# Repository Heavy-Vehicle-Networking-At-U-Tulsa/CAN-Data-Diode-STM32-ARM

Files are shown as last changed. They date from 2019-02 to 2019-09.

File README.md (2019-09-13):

# CAN Data Security Diode STM32 ARM
The code and documentation in this repository support a version of the CAN Data Security Diode that uses an ARM Cortex-M0 Processor with a CAN Controller made by ST. The specific chip use in this design is the [STM32F042K4](https://www.st.com/content/st_com/en/products/microcontrollers/stm32-32-bit-arm-cortex-mcus/stm32-mainstream-mcus/stm32f0-series/stm32f0x2/stm32f042k4.html).

## Documentation
The CAN Data Diode was presented at the 2019 ESCAR USA conference in Ypsilanti, MI. The [presentation slide deck](docs/2019_ESCAR_US_Daily2_Lecture.pdf) is in the docs folder. The [extended abstract](docs/CAN_Data_Diode_Abstract.pdf) aslo describes the system and the way it works. The design and production documents are available in this repository. 

## Source Code
The source code in this repository is built on [Example Code snippets](https://www.st.com/content/st_com/en/products/embedded-software/mcus-embedded-software/stm32-embedded-software/stm32snippets/stm32snippetsf0.html) covering STM32 F0 series.

## Hardware Documentation
The [documentation for the hardware](docs/README.md) includes schematics, production, files and original Altium Designer files.

## License


This work is licensed under a [Creative Commons Attribution-NonCommercial-ShareAlike 4.0 International License](http://creativecommons.org/licenses/by-nc-sa/4.0/) with the following addenda:

### Section 9 - Licensor
The Licensor for the works in this repository, unless otherwise noted, is The University of Tulsa, 800 S. Tucker Dr., Tulsa, OK, 74104. All inquiries regarding the potential for commercialization should be directed to the Office of Research and Sponsored Programs. 

### Section 10 - Licenced Material
The Licensed Material is the CAN Data Diode hardware design, which includes schematics, assembly instructions and documents (i.e. Gerber Files, NC Drill files, pick-and-place files, and the bill of materials). Unless otherwise noted in the source files, source code in this repository is included in the Licenced Material.

## Commercial Use
For commercial applications, please contact the University of Tulsa's Office of Research and Sponsored Programs for licensing opportunities.

## Acknowledgments
The authors and designers would like to acknowledge the support of the National Motor Freight Traffic Association, Inc. (NMFTA) in creating this device. Their leadership in the promoting and improving cybersecurity of heavy vehiles should not go unnoticed.

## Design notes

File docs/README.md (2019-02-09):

# CAN Data Diode Production Files and Documentation

This documentation directly focuses on the hardware design and production of the CAN Data Diode.

So long as the terms of the license are met, you can use these production and documentation files to fabricate, evaluate, and test the CAN Data Diode. 

## Documentation
The documentation consists of the following documents:

  1. The schematic drawing of the circuit used for the CAN Data Diode with the STM32F0 processors.
  1. A Bill of Materials in MS Excel and PDF formats.

## Production Files
The production files contain a zip compressed folder with the Gerber files, pick-and-place files, bill of materials, and NC drill files. This single zip file can be sent to an electronics fabrication facility for a full turn-key prodution. For example, Electronic Manufacturing Solutions, Inc. out of Lincoln, AR can produce these boards with the contents of this production file.

## Altium Files
The printed circuit board project files including the PCB layout and schematic are available. This is the so-called source code of the hardware for the CAN Data Diode. 

## Errata
On the first run articles produced in 2018, the Diodes D1 and D2 were mounted backwards. After orienting them correctly, the system powers on correctly.

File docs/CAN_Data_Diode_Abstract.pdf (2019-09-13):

Controller Area Network Security Data Diode Extended Abstract
Introduction
A controller area network (CAN) security data diode converts a stub of the linear CAN bus from being able to read and write to read-only. This effectively isolates a network node by preventing it from writing data to the network. The CAN data diode is a hardware-based solution that gives system integrators and vehicle owners the ability to take active steps in preventing any detrimental CAN traffic from affecting the normal operation of a vehicle. The original concept for the CAN security data diode was to isolate electronic logging devices (ELDs) on heavy vehicles, but the hardware device can be used to isolate any read-only node on a CAN bus (e.g. a radio).

### Problem Statement

Even though the controller area network protocol has reliable delivery mechanisms built in with the
acknowledgment field, CAN lacks message authentication mechanisms at the protocol level. This means unintended or malicious network traffic can be introduced to the system without recourse. Devices connected to the vehicle CAN networks are capable of both receiving and sending information with equal access to the direct-link vehicle network. A cybersecurity breach in any of the connected controller applications affecting the CAN communications can lead to serious consequences.
In new vertically integrated vehicle systems a designer can specify some application layer authentication mechanisms like checksums, or cryptographic message authentication code (CMAC). However, in legacy systems, aftermarket device installations, or horizontally integrated industries, like heavy vehicles, the ability to implement application layer protections is challenging. Furthermore, federal regulations, like the ELD mandate for heavy vehicles, may require the installation of wirelessly connected devices to a vehicle. The introduction of these ELD devices to the SAE J1939 network is required on all trucks that are so equipped, which reaches back as far as model year 2000 vehicles. Legacy fleets are now required to have wirelessly enabled electronic devices connected to the same controller area network that is used by the brakes, engine, instrument cluster. Vehicle manufacturers have little influence on the quality and security of the ELD devices connected on their vehicles.
Implementation
The CAN security data diode works by using two CAN transceivers in a configuration such that the transceiver connected to the main CAN bus (let’s call this the J1939 transceiver) has its receive data line (RXD) connected to the transmit data line (TXD) of a transceiver connected to the isolated node (let’s call this the ELD transceiver). This would act as a CAN relay where the J1939 transceiver would convert the differential CAN signal into a logic signal which is sent to the ELD transceiver to be converted back to the differential CAN signal. There is no inspection of or filtering of the data, so latency is minimized. However, the reverse connection is not made, so any data received from the ELD transceiver that would be sent out on the TXD logic pin is not received by the J1939 transceiver. Removing the connection from RXD of the ELD transceiver to the TXD of the J1939 transceiver eliminates the ability for messages generated from the isolated node to be seen on the main CAN bus.
Since the physical implementation of the diode functionality is based solely on hardware transceivers, there is no way for a software vulnerability to exist in the diode. To attack or circumvent the CAN data diode itself, someone could physically remove it from the wiring harness.
Dealing with messages on isolated nodes
While the intended use of the CAN security data diode is to enforce a read-only policy, there may be times when the isolated node would legitimately respond. For example, an isolated device may respond to a request for component information defined in SAE J1939. Another example is address claiming according to the SAE J1939 specification. If the back-to-back transceiver solution is deployed on its own, then the network on the isolated ELD side would be incomplete. Since the CAN controller is responsible for sending acknowledgment bits for received messages, the transceiver only implementation would not be able to satisfy this functionality. Without the ability for the isolated device to have its messages acknowledged, the messages will retry and accumulate errors. This may affect the functionality of the isolated device as it would be in an error state.

To alleviate the issue for a lack of acknowledgement, another CAN node needs to be present on the isolated bus. This node needs to contain both a controller and a transceiver with settings to match the bitrate of the original communications system. This new node on the isolated side of the network is build into the CAN data diode and is called the Acknowledger node.
Another challenge for an isolated ELD node when sending messages is arbitration. For the non-destructive media access control solution used by CAN to work, the nodes on the network need to be able to monitor the bus. When isolating a node, then the rest of the nodes cannot detect when the isolated node tries to transmit data. This means the main CAN bus will detect a quiet bus, even if the isolated node tries to transmit. Since the bus is quiet, the nodes on the J1939 side may begin transmitting, even if the isolated node is in the middle of transmitting a message. If this happens, bits may be flipped, or the CAN structure may be violated, and the isolated node will detect that it did not receive what it sent. This will initiate the error handling process on the isolated node. This process will likely try to send the message again during the next bus quiet phase, but the same issue may come up again. During times with heavy busloads, the process may repeat enough times for the isolated node on the ELD network to accumulate enough transmit error counts to enter an error passive or bus off state.
To prevent the effect of a so-called “chatty” main CAN bus sending the isolated node into an error state, the Acknowledger node built into the data diode will track error counts and be able to silence the ELD transceiver that is forwarding the busy traffic from the main CAN bus. This temporary respite for the isolated node enables a successful transmission from the isolated node on the ELD side of the network, which keeps the isolated node from going into an error passive or bus-off state.
ELD Request Proxy
In the case of an ELD that is governed by regulation, there are certain data elements that need to be requested according to the SAE J1939 standard. These elements include engine hours and vehicle identification number. Since these elements are required, it is likely that an ELD would request them using the SAE J1939 parameter group number for requesting data. However, if the ELD is isolated and cannot request this information, another device on the network must provide it. In some cases, these messages are requested by and among the modules already on the network. However, if they are not readily available during normal operation, then a so-called requester node will need to act as a requesting proxy for the ELD. This purpose-built device can be integrated into the CAN data diode or installed as a separate device. The requester should only request data elements if they are not already present. Both ISO 14229 messages and SAE J1939 message should be examined to look for the required data elements. Hardware Circuit Description
A reference design, as shown in the Appendix, was built using STMicroelectronics’ STM32F042G4 ARM Cortex-M0 microprocessors with built-in CAN controllers. These were coupled with Texas Instruments’ CAN transceivers from the TCAN33X family. In quantities of 100, the price per unit (including the enclosure) was $53.96 with USbased manufacturing for the prototype units.
There are four CAN transceivers; two of the transceivers are dedicated to the data diode functionality. The data diode transceivers are the TI-TCAN330 devices with silent mode and shutdown mode. The silent mode is controlled on pin 8 of the transceiver and is connected to the Acknowledger microprocessor. If the Acknowledger detects receive errors, which are likely from interference between the isolated node and the main CAN bus, then it will put the ELD transceiver into silent mode to prevent the transmission of data from the main bus to the isolated bus. The J1939 transceiver is always in silent mode. Pin 5 of the data diode transceivers are used to toggle the shutdown modes for the system to reduce power when the CAN bus is silent.
The remaining two CAN transceivers are connected to the STM32F0 processors. These are the TI TCAN334 that have a shutdown mode and a low power standby mode with wake. The standby mode enables the transceiver to wake with network traffic and to inform the requester microcontroller to activate the remaining transceivers. After a timeout period of low or reduced traffic, the microprocessors will enable the transceivers’ low power modes.
When a CAN security data diode is installed, it will automatically determine the best bit timing to match the bitrate of the vehicle network. The two most popular choices are 250,000 bps and 500,000 bps. The process of automatically determining the bitrate, or autobaud feature, leverages the receive error counter (REC) functionality of the CAN controller. The initial guess for the bit timing is loaded from a register in EEPROM. If REC increases when new messages arrive, a new value is tried until messages arrive. The new value is stored in the EEPROM, which will keep the unit from iterating over the valid bit timing combinations if the device is installed on the same vehicle (or a CAN bus with the same rate).
The CAN terminating resistors are also isolated with the CAN Data diode. Therefore, the ELD and Acknowledger transceivers are connected to a differential pair that has 60 ohms of resistance across the pair. Examination of the wave forms as observed with an oscilloscope on the differential signaling pair on either side of the CAN Data diode shows there is no recognizable lag in the signals from one side to another. In other words, any delay in the signal is influenced only by electronic wave propagation in the semiconductors since there is no filtering mechanism in place. The physical connectors to the CAN data diode reference use a DSUB 15 connector with two rows. The industry standard pinout has battery power on pin 8, ignition signal on pin 1, ground on pin 6, J1939H on pin 13, and J1939L on Pin 12. All other pins pass through. The raw battery and ignition connections are reverse polarity protected with a Schottky diode. Conductive noise suppression is handled by a hybrid varistor. Noise and Electrostatic Discharge protections are built into the CAN transceivers. All components selected for the reference build are AEC rated for an automotive environment.
If an ignition signal line is not present at the location of installation, then a resistor connects the conductive path for the ignition signal to the raw battery line, which pulls the ignition signal high. The Infineon linear Low Dropout (LDO) regulator supplies 3.3V to the board with a maximum current draw of 100mA when the enable pin is pulled high. The ignition line is connected to the enable pin for a hardware-based power regulation system. If the ignition line is not independent of the battery voltage, then the programming in the microprocessors will need to manage current draw when the vehicle is off. The reference design draws about 30 mA when on. The software for the Acknowledger and the Requester are programs that implement their necessary functions of initializing the hardware systems, setting the bit rates, and scheduling the processes for performing the requests and power monitoring. A CAN based updating systems was purposely not implemented as changes to the CAN data diode will need to be done with physical access. For the reference hardware, programming is done using a SWD enabled JTAG device. The board has the Cortex -M headers with ten pins (fine pitched). These programs are needed to isolate the ELD for heavy trucks and manage power saving features. The programming and debugging headers on the printed circuit board are to the outside of the rest of the functional circuits. This feature enables production without debug headers by simply changing the board outline.
Test Results
Test results up to 1 Mbps shows all CAN traffic flows from the J1939 side to the ELD side error free when the isolated ELD node is quiet. The acknowledger functions as desired can be observed through the CAN TX line sending out acknowledgment bits for every CAN message passing through the data diode. If the ELD side is “compromised” and tries a denial of service attack by flooding the bus, the CAN Data Diode isolates that attack and no disruption of the main CAN bus is noticed when observing with both an oscilloscope and a CAN data logger. Discussion and Conclusion
The CAN security data diode is well suited to isolate read-only nodes that may not have well understood security properties. Some of the earliest academic research by Koscher, et ali demonstrated a radio unit could be exploited to affect the CAN bus. If the radio does not need to write to the CAN bus, then the CAN data diode can guarantee read-only behavior and offers a robust security solution to protect against unknown security vulnerabilities in radio head units. Printed circuit board adaptations to accommodate J1962 OBD-II connectors are possible, which could enhance security for the diagnostic ports to accommodate installation of after-market devices to the diagnostics port. The CAN data diode is applicable wherever a read-only or monitoring device is installed, regardless of the vehicle or industry. Rail, busses, and maritime applications may have more opportunities for passengers to tamper with wiring or accessing the CAN bus in an unauthorized way. The CAN data diode can mitigate the effect of a threat actor accessing the CAN through a monitoring device. Asset tracking and data logging features are also good candidates to be isolated behind a CAN Data Diode. The CAN security data diode is a hardware-based solution to mitigate the effect of an exploited node on a CAN bus.

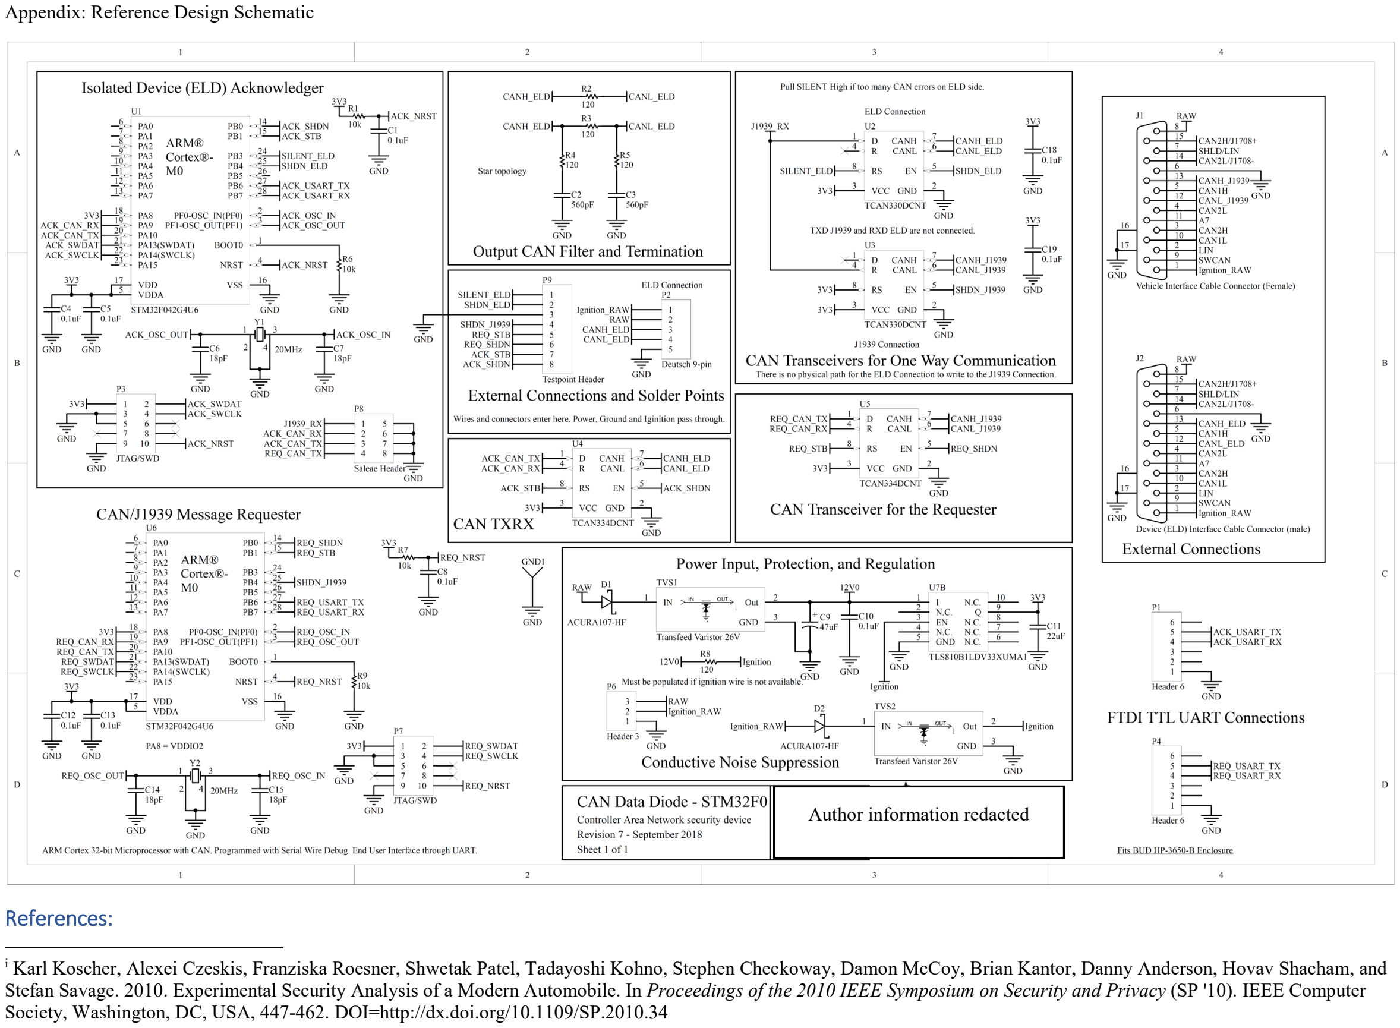
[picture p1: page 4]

Appendix: Reference Design Schematic

References:

i Karl Koscher, Alexei Czeskis, Franziska Roesner, Shwetak Patel, Tadayoshi Kohno, Stephen Checkoway, Damon McCoy, Brian Kantor, Danny Anderson, Hovav Shacham, and Stefan Savage. 2010. Experimental Security Analysis of a Modern Automobile. In Proceedings of the 2010 IEEE Symposium on Security and Privacy (SP '10). IEEE Computer Society, Washington, DC, USA, 447-462. DOI=http://dx.doi.org/10.1109/SP.2010.34

Author information redacted

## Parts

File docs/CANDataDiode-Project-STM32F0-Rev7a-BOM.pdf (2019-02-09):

Comment | Description | Designator | Footprint | Manufacturer 1 | Manufacturer Part Number 1 | Quantity | Supplier 1 | Supplier Part Number 1
0.1uF | 0.1µF ±10% 50V Ceramic Capacitor X7R 0402 (1005 Metric) | C1, C4, C5, C8, C10, C12, C13, C18, C19 | 0402 | TDK | CGA2B3X7R1H104K050BB | 9 | Digi-Key | 445-6899-1-ND
560pF | 560pF ±5% 50V Ceramic Capacitor CH 0402 (1005 Metric) | C2, C3 | 0402 | Taiyo Yuden | UMK105CH561JVHF | 2 | Digi-Key | 587-5093-1-ND
18pF | 18pF ±5% 50V Ceramic Capacitor C0G, NP0 0402 (1005 Metric) | C6, C7, C14, C15 | 0402 | Murata | GCM1555C1H180JA16D | 4 | Digi-Key | 490-12650-1-ND
47uF | 47µF 35V Aluminum Capacitors Radial, Can - SMD 5000 Hrs @ 105°C | C9 | Elec. Cap - D | Panasonic | EEE-HDV470XAP | 1 | Digi-Key | PCE4968CT-ND
22uF | 22µF ±20% 4V Ceramic Capacitor X7R 1206 (3216 Metric) | C11 | 1206 | Taiyo Yuden | AMK316AB7226MLHT | 1 | Digi-Key | 587-3267-1-ND
ACURA107-HF | Diode Schottky 1000V 1A Surface Mount DO-214AC (SMA) | D1, D2 | SMA with A and K | Comchip | ACURA107-HF | 2 | Digi-Key | 641-1884-1-ND
Vehicle Interface Cable Connector (Female) | Receptacle Assembly, 15 Position, Right Angle | J1 | DSUB1.385-2H15 | Amphenol FCI | D15S33E4GV00LF | 1 | Digi-Key | 609-1498-ND
Device (ELD) Interface Cable Connector (male) | Receptacle Assembly, 15 Position, Right Angle | J2 | DSUB1.385-2H15 | Amphenol FCI | D15P33E4GV00LF | 1 | Digi-Key | 609-1492-ND
10k | 10 kOhms ±0.5% 0.063W, 1/16W Chip Resistor 0402 (1005 Metric) Anti-Sulfur, Automotive AEC-Q200 Thin Film | R1, R6, R7, R9 | 0402 | Susumu | RG1005P-103-D-T10 | 4 | Digi-Key | RG10P10.0KDCT-ND
120 | 120 Ohms ±1% 0.063W, 1/16W Chip Resistor 0402 (1005 Metric) Automotive AEC-Q200 Thick Film | R2, R3, R4, R5, R8 | 0402 | Vishay | CRCW0402120RFKED | 5 | Digi-Key | 541-120LCT-ND
Transfeed Varistor 26V | 34.5V 80A Varistor 1 Circuit Surface Mount 0805 (2012 Metric) | TVS1, TVS2 | Transfeed | Kyocera AVX | V2AF126C600Y2EDP | 2 | Digi-Key | 478-10038-1-ND
STM32F042G4U6 | ARM® Cortex®-M0 STM32F0 Microcontroller IC 32-Bit 48MHz 16KB (16K x 8) FLASH 28-UFQFPN (4x4) | U1, U6 | STM-UFQFPN28_V | STMicroelectronics | STM32F042G4U6 | 2 | Digi-Key | 497-17830-ND
TCAN330DCNT | IC TXRX CAN 3.3V SOT23-8 | U2, U3 | SOT65P280X145-8N | Texas Instruments | TCAN330DCNT | 2 | Digi-Key | 296-44210-1-ND
TCAN334DCNT | IC TXRX CAN 3.3V SOT23-8 | U4, U5 | SOT65P280X145-8N | Texas Instruments | TCAN334DCNT | 2 | Digi-Key | 296-44503-1-ND
TLS810B1LDV33XUMA1 | Linear Voltage Regulator IC 1 Output 100mA PG-TSON-10 | U7 | SON50P330X110 _HS-11N | Infineon | TLS810B1LDV33XUMA1 | 1 | Digi-Key | TLS810B1LDV33XUMA1CT-ND
20MHz | 20MHz ±30ppm Crystal 18pF 60 Ohms 4-SMD, No Lead | Y1, Y2 | XTAL 4 pad | ECS International | ECS-200-18-33Q-DS | 2 | Digi-Key | XC1998CT-ND

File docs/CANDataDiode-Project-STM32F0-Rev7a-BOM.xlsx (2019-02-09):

Comment | Description | Designator | Footprint | Manufacturer 1 | Manufacturer Part Number 1 | Quantity | Supplier 1 | Supplier Part Number 1
0.1uF | 0.1µF ±10% 50V Ceramic Capacitor X7R 0402 (1005 Metric) | C1, C4, C5, C8, C10, C12, C13, C18, C19 | 0402 | TDK (https://octopart-clicks.com/click/altium?sku=445-6899-1-ND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) | CGA2B3X7R1H104K050BB (https://octopart-clicks.com/click/altium?sku=445-6899-1-ND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) | 9 | Digi-Key | 445-6899-1-ND (https://octopart-clicks.com/click/altium?sku=445-6899-1-ND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)
560pF | 560pF ±5% 50V Ceramic Capacitor CH 0402 (1005 Metric) | C2, C3 | 0402 | Taiyo Yuden (https://octopart-clicks.com/click/altium?sku=587-5093-1-ND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) | UMK105CH561JVHF (https://octopart-clicks.com/click/altium?sku=587-5093-1-ND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) | 2 | Digi-Key | 587-5093-1-ND (https://octopart-clicks.com/click/altium?sku=587-5093-1-ND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)
18pF | 18pF ±5% 50V Ceramic Capacitor C0G, NP0 0402 (1005 Metric) | C6, C7, C14, C15 | 0402 | Murata (https://octopart-clicks.com/click/altium?sku=490-12650-1-ND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) | GCM1555C1H180JA16D (https://octopart-clicks.com/click/altium?sku=490-12650-1-ND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) | 4 | Digi-Key | 490-12650-1-ND (https://octopart-clicks.com/click/altium?sku=490-12650-1-ND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)
47uF | 47µF 35V Aluminum Capacitors Radial, Can - SMD 5000 Hrs @ 105°C | C9 | Elec. Cap - D | Panasonic (https://octopart-clicks.com/click/altium?sku=PCE4968CT-ND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) | EEE-HDV470XAP (https://octopart-clicks.com/click/altium?sku=PCE4968CT-ND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) | 1 | Digi-Key | PCE4968CT-ND (https://octopart-clicks.com/click/altium?sku=PCE4968CT-ND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)
22uF | 22µF ±20% 4V Ceramic Capacitor X7R 1206 (3216 Metric) | C11 | 1206 | Taiyo Yuden (https://octopart-clicks.com/click/altium?sku=587-3267-1-ND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) | AMK316AB7226MLHT (https://octopart-clicks.com/click/altium?sku=587-3267-1-ND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) | 1 | Digi-Key | 587-3267-1-ND (https://octopart-clicks.com/click/altium?sku=587-3267-1-ND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)
ACURA107-HF | Diode Schottky 1000V 1A Surface Mount DO-214AC (SMA) | D1, D2 | SMA with A and K | Comchip (https://octopart-clicks.com/click/altium?sku=641-1884-1-ND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) | ACURA107-HF (https://octopart-clicks.com/click/altium?sku=641-1884-1-ND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) | 2 | Digi-Key | 641-1884-1-ND (https://octopart-clicks.com/click/altium?sku=641-1884-1-ND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)
Vehicle Interface Cable Connector (Female) | Receptacle Assembly, 15 Position, Right Angle | J1 | DSUB1.385-2H15 | Amphenol FCI (https://octopart-clicks.com/click/altium?sku=609-1498-ND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) | D15S33E4GV00LF (https://octopart-clicks.com/click/altium?sku=609-1498-ND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) | 1 | Digi-Key | 609-1498-ND (https://octopart-clicks.com/click/altium?sku=609-1498-ND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)
Device (ELD) Interface Cable Connector (male) | Receptacle Assembly, 15 Position, Right Angle | J2 | DSUB1.385-2H15 | Amphenol FCI (https://octopart-clicks.com/click/altium?sku=609-1492-ND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) | D15P33E4GV00LF (https://octopart-clicks.com/click/altium?sku=609-1492-ND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) | 1 | Digi-Key | 609-1492-ND (https://octopart-clicks.com/click/altium?sku=609-1492-ND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)
10k | 10 kOhms ±0.5% 0.063W, 1/16W Chip Resistor 0402 (1005 Metric) Anti-Sulfur, Automotive AEC-Q200 Thin Film | R1, R6, R7, R9 | 0402 | Susumu (https://octopart-clicks.com/click/altium?sku=RG10P10.0KDCT-ND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) | RG1005P-103-D-T10 (https://octopart-clicks.com/click/altium?sku=RG10P10.0KDCT-ND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) | 4 | Digi-Key | RG10P10.0KDCT-ND (https://octopart-clicks.com/click/altium?sku=RG10P10.0KDCT-ND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)
120 | 120 Ohms ±1% 0.063W, 1/16W Chip Resistor 0402 (1005 Metric) Automotive AEC-Q200 Thick Film | R2, R3, R4, R5, R8 | 0402 | Vishay (https://octopart-clicks.com/click/altium?sku=541-120LCT-ND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) | CRCW0402120RFKED (https://octopart-clicks.com/click/altium?sku=541-120LCT-ND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) | 5 | Digi-Key | 541-120LCT-ND (https://octopart-clicks.com/click/altium?sku=541-120LCT-ND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)
Transfeed Varistor 26V | 34.5V 80A Varistor 1 Circuit Surface Mount 0805 (2012 Metric) | TVS1, TVS2 | Transfeed | Kyocera AVX (https://octopart-clicks.com/click/altium?sku=478-10038-1-ND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) | V2AF126C600Y2EDP (https://octopart-clicks.com/click/altium?sku=478-10038-1-ND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) | 2 | Digi-Key | 478-10038-1-ND (https://octopart-clicks.com/click/altium?sku=478-10038-1-ND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)
STM32F042G4U6 | ARM® Cortex®-M0 STM32F0 Microcontroller IC 32-Bit 48MHz 16KB (16K x 8) FLASH 28-UFQFPN (4x4) | U1, U6 | STM-UFQFPN28_V | STMicroelectronics (https://octopart-clicks.com/click/altium?sku=497-17830-ND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) | STM32F042G4U6 (https://octopart-clicks.com/click/altium?sku=497-17830-ND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) | 2 | Digi-Key | 497-17830-ND (https://octopart-clicks.com/click/altium?sku=497-17830-ND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)
TCAN330DCNT | IC TXRX CAN 3.3V SOT23-8 | U2, U3 | SOT65P280X145-8N | Texas Instruments (https://octopart-clicks.com/click/altium?sku=296-44210-1-ND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) | TCAN330DCNT (https://octopart-clicks.com/click/altium?sku=296-44210-1-ND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) | 2 | Digi-Key | 296-44210-1-ND (https://octopart-clicks.com/click/altium?sku=296-44210-1-ND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)
TCAN334DCNT | IC TXRX CAN 3.3V SOT23-8 | U4, U5 | SOT65P280X145-8N | Texas Instruments (https://octopart-clicks.com/click/altium?sku=296-44503-1-ND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) | TCAN334DCNT (https://octopart-clicks.com/click/altium?sku=296-44503-1-ND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) | 2 | Digi-Key | 296-44503-1-ND (https://octopart-clicks.com/click/altium?sku=296-44503-1-ND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)
TLS810B1LDV33XUMA1 | Linear Voltage Regulator IC 1 Output 100mA PG-TSON-10 | U7 | SON50P330X110_HS-11N | Infineon (https://octopart-clicks.com/click/altium?manufacturer=Infineon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) | TLS810B1LDV33XUMA1 (https://octopart-clicks.com/click/altium?manufacturer=Infineon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) | 1 | Digi-Key | TLS810B1LDV33XUMA1CT-ND (https://octopart-clicks.com/click/altium?manufacturer=Infineon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)
20MHz | 20MHz ±30ppm Crystal 18pF 60 Ohms 4-SMD, No Lead | Y1, Y2 | XTAL 4 pad | ECS International (https://octopart-clicks.com/click/altium?sku=XC1998CT-ND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) | ECS-200-18-33Q-DS (https://octopart-clicks.com/click/altium?sku=XC1998CT-ND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) | 2 | Digi-Key | XC1998CT-ND (https://octopart-clicks.com/click/altium?sku=XC1998CT-ND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)

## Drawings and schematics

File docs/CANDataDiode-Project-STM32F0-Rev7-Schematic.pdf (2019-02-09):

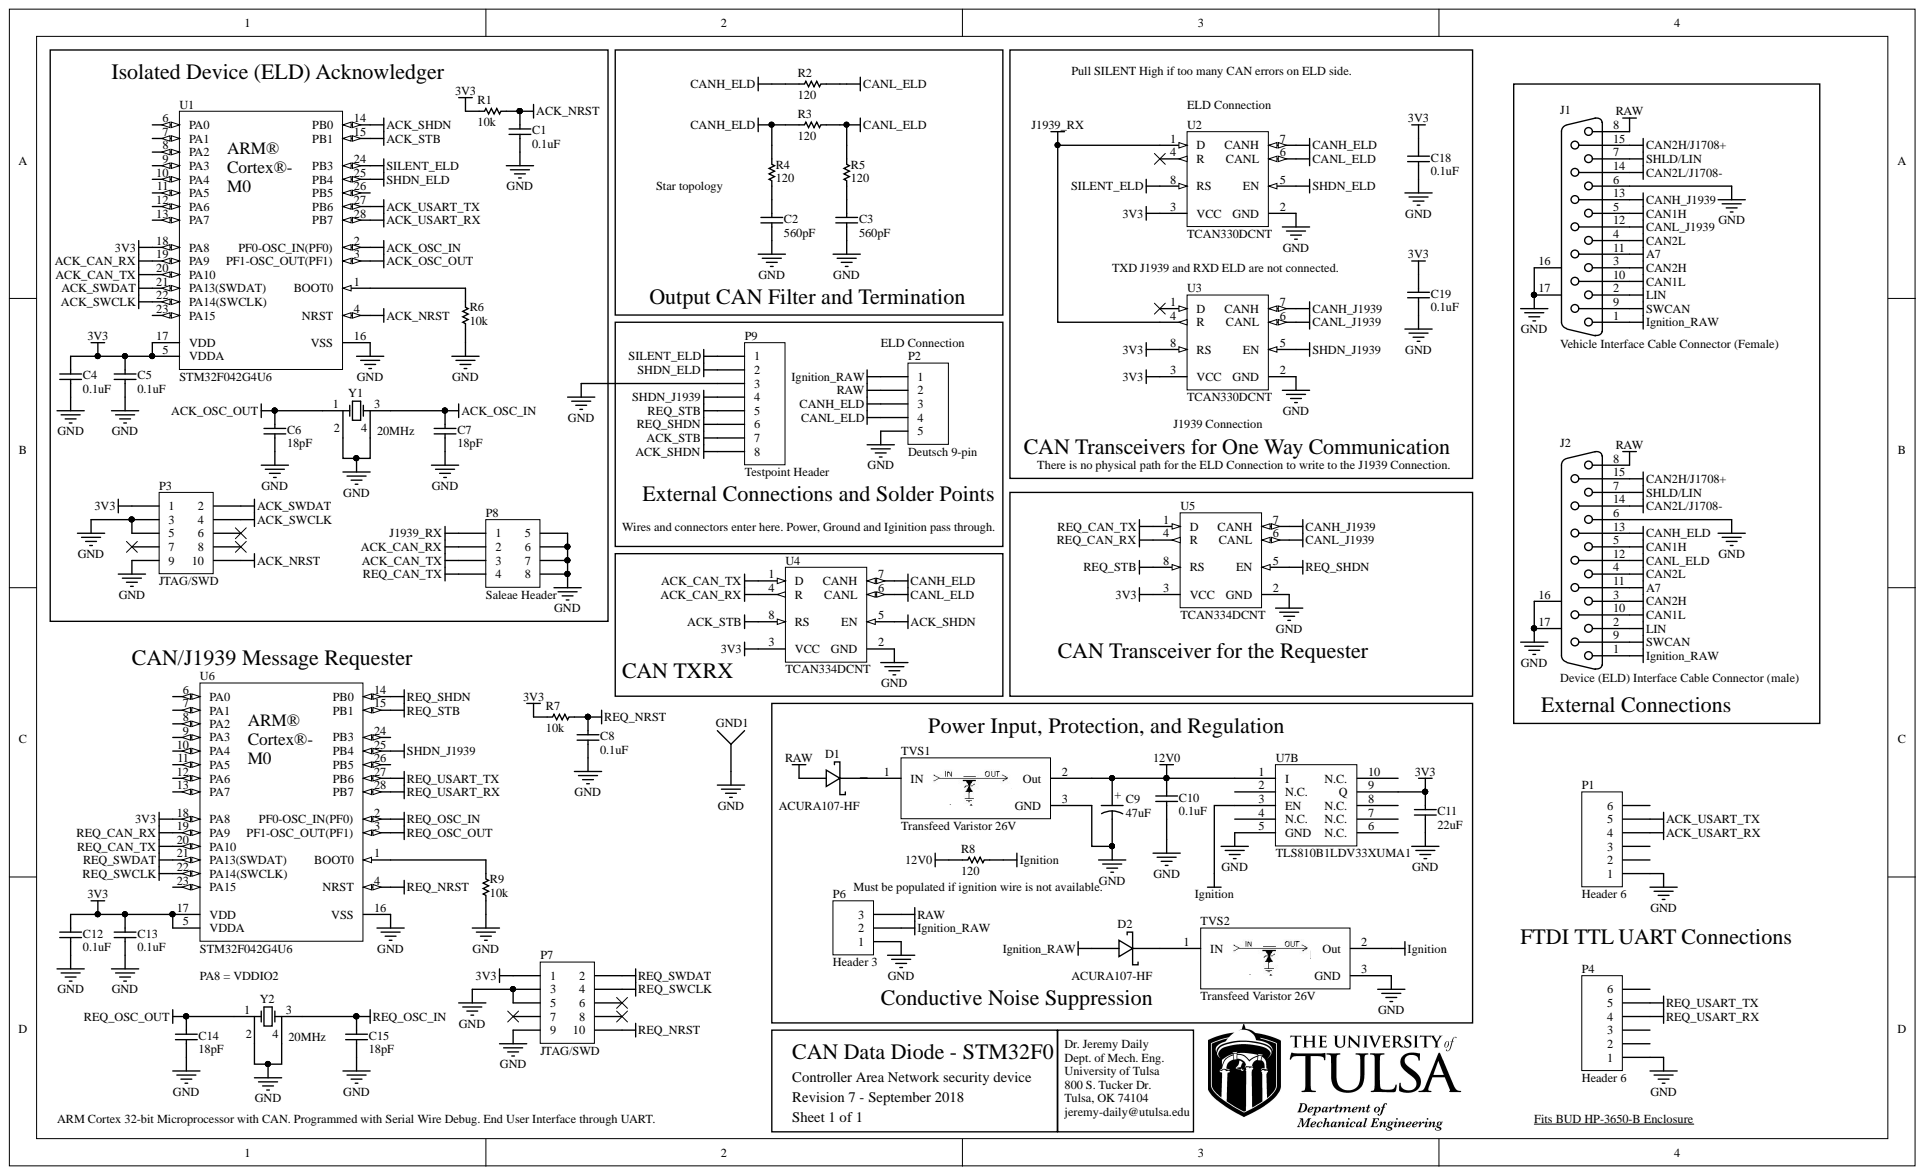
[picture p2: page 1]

Pull SILENT High if too many CAN errors on ELD side.

J1Vehicle Interface Cable Connector (Female)

TXD J1939 and RXD ELD are not connected.

Output CAN Filter and

There is no physical path for the ELD Connection to write to the J1939 Connection.

Wires and connectors enter here. Power

, Ground and Iginition pass through.

XRX CAN/J1939 Message Requester

Transceiver for the Requester

Device (ELD) Interface Cable Connector (male)
External Connections

Must be populated if ignition wire is not available.

Dept. of Mech. Eng.
University of
Tulsa, OK 74104
jeremy-daily@utulsa.edu

CAN Data Diode - STM32F0 Controller Area Network security device Revision 7 - September 2018

ARM Cortex 32-bit Microprocessor with CAN. Programmed with Serial

Wire Debug. End User Interface through UART

Fits BUD HP-3650-B Enclosure (https://www.budind.com/pdf/hb3650.pdf)

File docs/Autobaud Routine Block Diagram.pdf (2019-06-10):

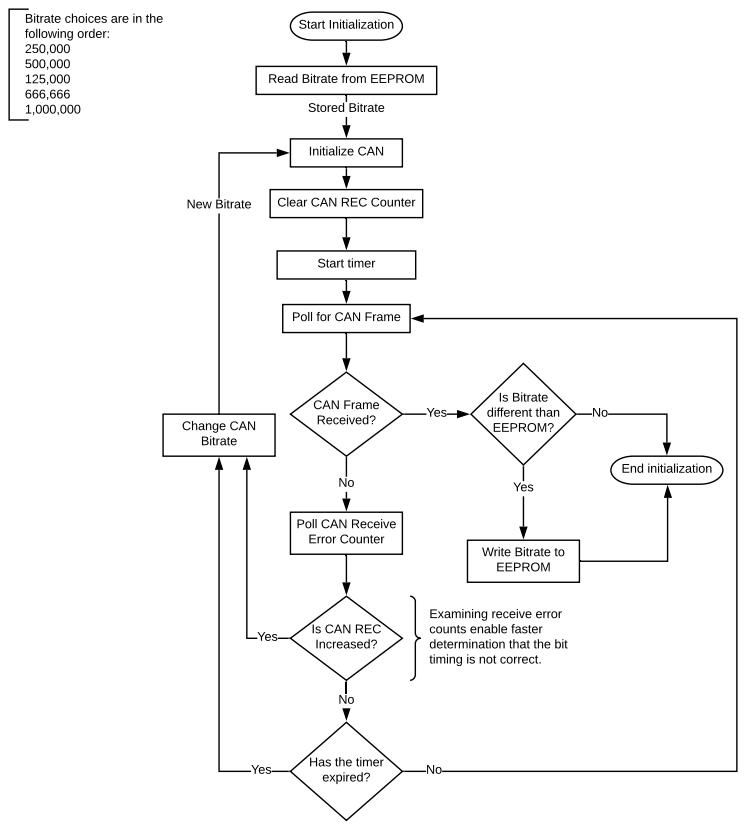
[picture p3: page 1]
Start Initialization; Initialize CAN; Stored Bitrate; CAN Frame Received?; Change CAN Bitrate; Yes; Is Bitrate different than EEPROM?; End initialization; expired? Yes; New Bitrate; Start timer; Bitrate choices are in the following order: 250,000 500,000 125,000 666,666 1,000,000

Read Bitrate from EEPROM

Clear CAN REC Counter

Poll for CAN Frame

Poll CAN Receive
Error Counter

Write Bitrate to
EEPROM

Examining receive error
counts enable faster
determination that the bit
timing is not correct.

Is CAN REC
Increased?

Has the timer

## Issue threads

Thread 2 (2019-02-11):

Copyright of `main.c` is assigned (incompatibly) to ST Micro

BenGardiner, 2019-02-11:
https://github.com/Heavy-Vehicle-Networking-At-U-Tulsa/CAN-Data-Diode-STM32-ARM/blob/c5b273675d3bb0c0fc5f10308ce3028178a4fffb/src/main.c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

jeremydaily, 2019-02-11:
This is ST's code and I need to leave the copyright intact. This section would not fall under the CC license or any other license that I come up with because it is already copyrighted material. Suggestions?

BenGardiner, 2019-02-11:
Hmmmm. OK.

I suggest starting from scratch for the ELD-side and J1939-side `*.c` source files then.

BenGardiner, 2019-02-14:
The software doesn't contain anything wrt the patents right? You should be able to license this as MIT or other permissive license like Attribution-ShareAlike https://creativecommons.org/licenses/ and publish that along with the paper.

This would allow you to simply implement the 'requestor list' as hard-coded array and users could rebuild (for now, until a slicker solution is implemented).

NB: CC-BY-SA 4.0 is GPLv3 compatible https://www.fsf.org/blogs/licensing/creative-commons-by-sa-4-0-declared-one-way-compatible-with-gnu-gpl-version-3

jeremydaily, 2019-02-14:
I'm planning to use an MIT license for file in any new source code for the system. The license in the individual source files should override the repository license, right?

BenGardiner, 2019-02-14:
Cool. MIT is fine. And yes, licenses _in_ the source files supersede those
in the LICENSE file of the repo. Plus, your README.md states that
explicitly. It's all good.

On Thu, Feb 14, 2019 at 9:21 AM Jeremy Daily <notifications@github.com>
wrote:

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

Closed 2019-02-14.

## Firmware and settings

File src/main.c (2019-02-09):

/**
  ******************************************************************************
  * @file    01_ConfigurationTransmissionReception/main.c 
  * @author  MCD Application Team
  * @version V1.2.0
  * @date    19-June-2015
  * @brief   This code example shows how to configure the GPIOs and bxCAN
  *          in order to transmit and receive in loopback mode.
  *
 ===============================================================================
                    #####       MCU Resources     #####
 ===============================================================================
   - bxCAN
   - Systick
   - GPIO  PA0, PC8, PC9,
           PA11(CAN_RX), PA12(CAN_TX)
   - RCC
   
 ===============================================================================
                    ##### How to use this example #####
 ===============================================================================
   - this file must be inserted in a project containing  the following files :
      o system_stm32f0xx.c, startup_stm32f072xb.s
      o stm32f0xx.h to get the register definitions
      o CMSIS files

 ===============================================================================
                    ##### How to test this example #####
 ===============================================================================
   - Launch the program
   - Press the user button
   - The orange LED toggles 
     (that's means a message is well transmit and received in loopback mode)
   - The transmit frame can be check with an oscilloscope on PA12
     (with SB20 fitted)
  *    
  ******************************************************************************
  * @attention
  *
  * <h2><center>&copy; COPYRIGHT 2015 STMicroelectronics</center></h2>
  *
  * Licensed under MCD-ST Liberty SW License Agreement V2, (the "License");
  * You may not use this file except in compliance with the License.
  * You may obtain a copy of the License at:
  *
  *        http://www.st.com/software_license_agreement_liberty_v2
  *
  * Unless required by applicable law or agreed to in writing, software 
  * distributed under the License is distributed on an "AS IS" BASIS, 
  * WITHOUT WARRANTIES OR CONDITIONS OF ANY KIND, either express or implied.
  * See the License for the specific language governing permissions and
  * limitations under the License.
  *
  ******************************************************************************
  */

/* Includes ------------------------------------------------------------------*/
#include "stm32f0xx.h"

/** @addtogroup STM32F0_Snippets
  * @{
  */

/* Private typedef -----------------------------------------------------------*/
/* Private define ------------------------------------------------------------*/
#define CMD_TOGGLE (0xDA)
#define CAN_ID_MASK (0xFF70U)
#define CAN_ID1 (0x651U)
#define CAN_ID2 (0x652U)
#define FILTER_LIST (0) /* 0: filter mode = identifier mask, 1: filter mode = identifier list */

/* Private macro -------------------------------------------------------------*/
/* Private variables ---------------------------------------------------------*/
/* Private function prototypes -----------------------------------------------*/
void Configure_GPIO_LED(void);
void Configure_GPIO_CAN(void);
void Configure_CAN(void);
void Configure_GPIO_Button(void);
void Configure_EXTI(void);

/* Private functions ---------------------------------------------------------*/

/**
  * @brief  Main program.
  * @param  None
  * @retval None
  */
int main(void)
{

  /*!< At this stage the microcontroller clock setting is already configured, 
       this is done through SystemInit() function which is called from startup
       file (startup_stm32f072xb.s) before to branch to application main.
       To reconfigure the default setting of SystemInit() function, refer to
       system_stm32f0xx.c file
     */

  Configure_GPIO_LED();
  Configure_GPIO_CAN();
  Configure_CAN();
  Configure_GPIO_Button();
  Configure_EXTI();

  /* Infinite loop */
  while (1)
  {
  }
}

/**
  * @brief  This function :
             - Enables GPIO clock
             - Configures the Green LED pin on GPIO PC9
             - Configures the Orange LED pin on GPIO PC8
  * @param  None
  * @retval None
  */
__INLINE void Configure_GPIO_LED(void)
{
  /* Enable the peripheral clock of GPIOC */
  RCC->AHBENR |= RCC_AHBENR_GPIOCEN;
	
  /* Select output mode (01) on PC8 and PC9 */
  GPIOC->MODER = (GPIOC->MODER & ~(GPIO_MODER_MODER8 | GPIO_MODER_MODER9)) \
                 | (GPIO_MODER_MODER8_0 | GPIO_MODER_MODER9_0);
}

/**
  * @brief  This function :
             - Enables GPIO clock
             - Configures the CAN pins on GPIO PA11 PA12
  * @param  None
  * @retval None
  */
__INLINE void Configure_GPIO_CAN(void)
{
  /* Enable the peripheral clock of GPIOA */
  RCC->AHBENR |= RCC_AHBENR_GPIOAEN;
	
  /* GPIO configuration for CAN signals */
  /* (1) Select AF mode (10) on PA11 and PA12 */
  /* (2) AF4 for CAN signals */
  GPIOA->MODER = (GPIOA->MODER & ~(GPIO_MODER_MODER11 | GPIO_MODER_MODER12))\
                 | (GPIO_MODER_MODER11_1 | GPIO_MODER_MODER12_1); /* (1) */
  GPIOA->AFR[1] = (GPIOA->AFR[1] &~ (GPIO_AFRH_AFRH3 | GPIO_AFRH_AFRH4))\
                  | (4 << (3 * 4)) | (4 << (4 * 4)); /* (2) */
}

/**
  * @brief  This function configures CAN.
  * @param  None
  * @retval None
  */
__INLINE void Configure_CAN(void)
{
  /* Enable the peripheral clock CAN */
  RCC->APB1ENR |= RCC_APB1ENR_CANEN;

  /* Configure CAN */
  /* (1) Enter CAN init mode to write the configuration */
  /* (2) Wait the init mode entering */
  /* (3) Exit sleep mode */
  /* (4) Loopback mode, set timing to 1Mb/s: BS1 = 4, BS2 = 3, prescaler = 6 */
  /* (5) Leave init mode */
  /* (6) Wait the init mode leaving */
  /* (7) Enter filter init mode, (16-bit + mask, filter 0 for FIFO 0) */
  /* (8) Acivate filter 0 */
  /* (9) Identifier list mode */
  /* (11) Set the Id list */
  /* (12) Set the Id + mask (all bits of standard id will care) */
  /* (13) Leave filter init */
  /* (14) Set FIFO0 message pending IT enable */
  CAN->MCR |= CAN_MCR_INRQ; /* (1) */
  while((CAN->MSR & CAN_MSR_INAK)!=CAN_MSR_INAK) /* (2) */
  { 
    /* add time out here for a robust application */
  }
  CAN->MCR &=~ CAN_MCR_SLEEP; /* (3) */
  CAN->BTR |= CAN_BTR_LBKM | 2 << 20 | 3 << 16 | 5 << 0; /* (4) */ 
  CAN->MCR &=~ CAN_MCR_INRQ; /* (5) */
  while((CAN->MSR & CAN_MSR_INAK)==CAN_MSR_INAK) /* (6) */
  { 
    /* add time out here for a robust application */
  }  
  CAN->FMR = CAN_FMR_FINIT; /* (7) */ 
  CAN->FA1R = CAN_FA1R_FACT0; /* (8) */
#if (FILTER_LIST)  
  CAN->FM1R = CAN_FM1R_FBM0; /* (9) */
  CAN->sFilterRegister[0].FR1 = CAN_ID2 << 5 | CAN_ID1 << (16+5); /* (10) */ 
#else  
  CAN->sFilterRegister[0].FR1 = CAN_ID1 << 5 | CAN_ID_MASK << 16; /* (11) */
#endif /* FILTER_LIST */
  
  CAN->FMR &=~ CAN_FMR_FINIT; /* (12) */
  CAN->IER |= CAN_IER_FMPIE0; /* (13) */
  
  /* Configure IT */
  /* (14) Set priority for CAN_IRQn */
  /* (15) Enable CAN_IRQn */
  NVIC_SetPriority(CEC_CAN_IRQn, 0); /* (16) */
  NVIC_EnableIRQ(CEC_CAN_IRQn); /* (17) */
}

/**
  * @brief  This function :
             - Enables GPIO clock
             - Configures the Push Button GPIO PA0
  * @param  None
  * @retval None
  */
__INLINE void Configure_GPIO_Button(void)
{
  /* Enable the peripheral clock of GPIOA */
  RCC->AHBENR |= RCC_AHBENR_GPIOAEN;
	
  /* Select mode */
  /* Select input mode (00) on PA0 */
  GPIOA->MODER = (GPIOA->MODER & ~(GPIO_MODER_MODER0));
}

/**
  * @brief  This function configures EXTI.
  * @param  None
  * @retval None
  */
__INLINE void Configure_EXTI(void)
{
  /* Configure Syscfg, exti and nvic for pushbutton PA0 */
  /* (1) PA0 as source input */
  /* (2) unmask port 0 */
  /* (3) Rising edge */
  /* (4) Set priority */
  /* (5) Enable EXTI0_1_IRQn */
  SYSCFG->EXTICR[0] = (SYSCFG->EXTICR[0] & ~SYSCFG_EXTICR1_EXTI0) | SYSCFG_EXTICR1_EXTI0_PA; /* (1) */ 
  EXTI->IMR |= EXTI_IMR_MR0; /* (2) */ 
  EXTI->RTSR |= EXTI_RTSR_TR0; /* (3) */ 
  NVIC_SetPriority(EXTI0_1_IRQn, 0); /* (4) */ 
  NVIC_EnableIRQ(EXTI0_1_IRQn); /* (5) */ 
}

/******************************************************************************/
/*            Cortex-M0 Processor Exceptions Handlers                         */
/******************************************************************************/

/**
  * @brief  This function handles NMI exception.
  * @param  None
  * @retval None
  */
void NMI_Handler(void)
{
}

/**
  * @brief  This function handles Hard Fault exception.
  * @param  None
  * @retval None
  */
void HardFault_Handler(void)
{
  /* Go to infinite loop when Hard Fault exception occurs */
  while (1)
  {
  }
}

/**
  * @brief  This function handles SVCall exception.
  * @param  None
  * @retval None
  */
void SVC_Handler(void)
{
}

/**
  * @brief  This function handles PendSVC exception.
  * @param  None
  * @retval None
  */
void PendSV_Handler(void)
{
}

/**
  * @brief  This function handles SysTick Handler.
  * @param  None
  * @retval None
  */
void SysTick_Handler(void)
{
}


/**
  * @brief  This function handles EXTI 0 1 interrupt request.
  * @param  None
  * @retval None
  */
void EXTI0_1_IRQHandler(void)
{
  EXTI->PR |= 1;
  
  if((CAN->TSR & CAN_TSR_TME0) == CAN_TSR_TME0)/* check mailbox 0 is empty */
  {
    CAN->sTxMailBox[0].TDTR = 1; /* fill data length = 1 */
    CAN->sTxMailBox[0].TDLR = CMD_TOGGLE; /* fill 8-bit data */
    CAN->sTxMailBox[0].TIR = (uint32_t)(CAN_ID1 << 21 | CAN_TI0R_TXRQ); /* fill Id field and request a transmission */
  }
  else
  {
    CAN->TSR |= CAN_TSR_ABRQ0; /* abort transmission if not empty */
  }
}

/**
  * @brief  This function handles CAN interrupt request.
  * @param  None
  * @retval None
  */
void CEC_CAN_IRQHandler(void)
{
  uint32_t CAN_ReceiveMessage = 0;

  if((CAN->RF0R & CAN_RF0R_FMP0)!=0)/* check if a message is filtered and received by FIFO 0 */
  {
    CAN_ReceiveMessage = CAN->sFIFOMailBox[0].RDLR; /* read data */
    CAN->RF0R |= CAN_RF0R_RFOM0; /* release FIFO */
    if((CAN_ReceiveMessage & 0xFF) == CMD_TOGGLE)
    {
      GPIOC->ODR ^= GPIO_ODR_8; /* Toggle orange LED */
    }
  }
}


/**
  * @}
  */

/************************ (C) COPYRIGHT STMicroelectronics *****END OF FILE****/
